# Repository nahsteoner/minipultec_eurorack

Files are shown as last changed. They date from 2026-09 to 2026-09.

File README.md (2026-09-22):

# OnerLAB BoCu

Module Eurorack **stéréo de fin de chaîne** : EQ type Pultec (sans tubes) + saturation douce à diodes + sorties jack 6,35 mm balanced.

- **Format** : 16 HP, 3U, alimentation ±12 V (header Doepfer 10 broches)
- **Entrées** : 2 × jack 3,5 mm mono (standard Eurorack), normalisées L → R
- **Sorties** : 2 × jack 6,35 mm TRS balanced (L / R)
- **PCB** : KiCad 7, netlist complète, **non routé** (placement fin + autorouter à ta main)
- **Fab** : pensé JLCPCB / LCSC, SMD 0603/0805 + SOIC-8

## Face avant

```
        OnerLAB BoCu
   [ LOW BOOST ]   [ LOW CUT ]
        [FREQ L] [FREQ R]     40 / 80 / 120 Hz
   [ MID CUT   ]   [ HIGH BOOST ]
   (LED sat L)         (LED sat R)
   IN L   IN R      OUT L   OUT R     ← jacks en bas
```

Les 4 pots sont **double piste** (L+R ensemble). Les deux rotatifs de fréquence sont **indépendants** (L et R).

## Le circuit, en une phrase

Buffer d'entrée → pad passif + mid-cut à gyrator → low-cut RC → makeup NE5532 avec **boost grave RLC (gyrator 11 H)** et **shelf aigu**, diodes Si/LED asymétriques dans la contre-réaction, puis driver balanced (hot + inverseur).

C'est un Pultec « inventé » en solide :

| Contrôle | Comportement simulé |
|---|---|
| Low boost | cloche ~+10 dB à 40 / 80 / 120 Hz, Q ≈ 1 |
| Low cut | shelf grave ~−11 dB, coin un peu au-dessus de f₀ |
| **Les deux** | le **Pultec trick** : bosse sur f₀ + creux de mud juste au-dessus |
| Mid cut | cloche ~−9 dB vers 500 Hz |
| High boost | shelf +8 à +10 dB vers 8–16 kHz |
| Diodes | propre à bas niveau (THD 0,08 % @ 0,5 V), couleur paire type lampe dès ~1,5 V |

Courbes : [`docs/curves/`](docs/curves/)

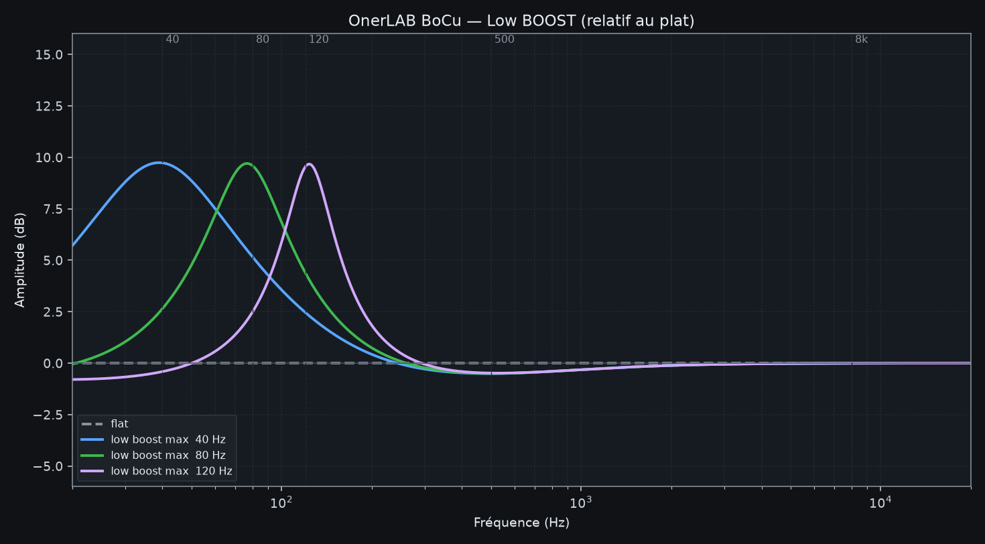
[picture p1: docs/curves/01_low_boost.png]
low boost

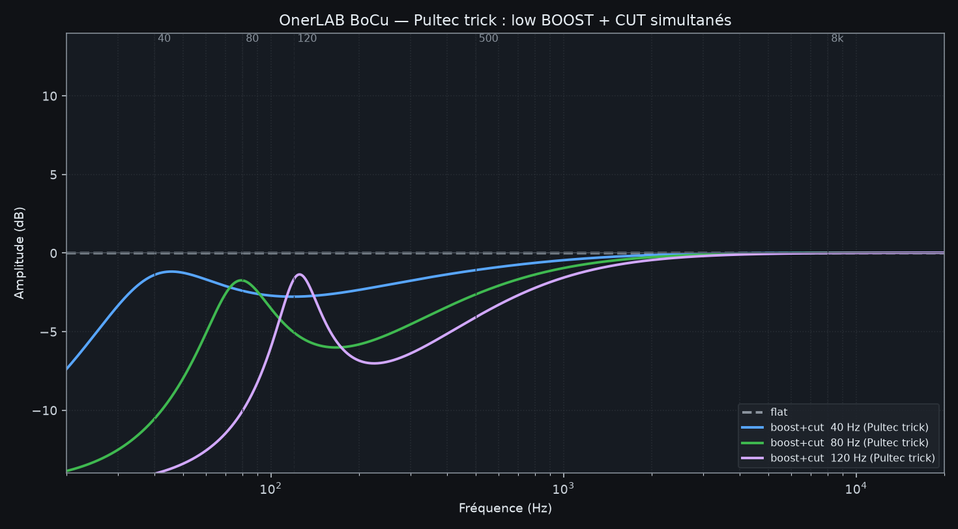
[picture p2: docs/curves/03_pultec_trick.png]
pultec trick

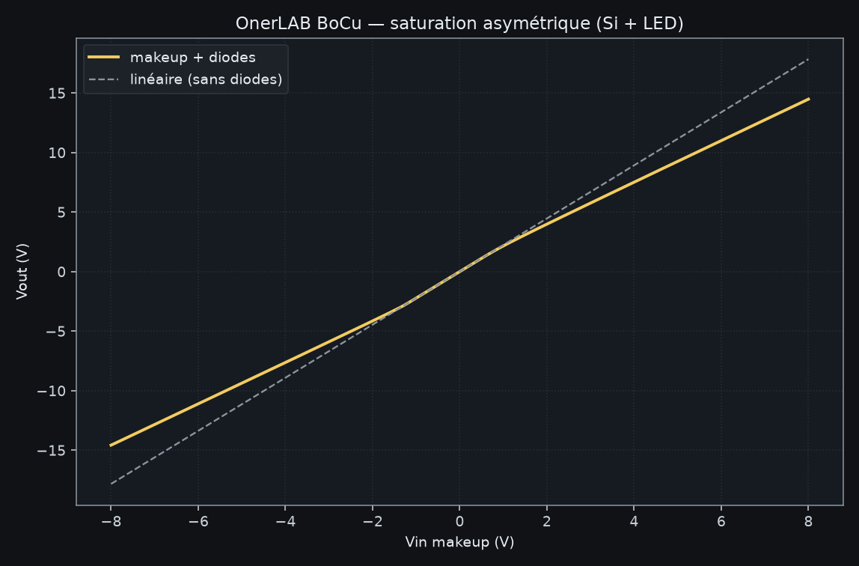
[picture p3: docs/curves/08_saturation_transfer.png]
saturation


Relancer les sims : `python3 sim/simulate_bocu.py`

## Fichiers KiCad

| Fichier | Rôle |
|---|---|
| `hardware/OnerLAB_BoCu.kicad_pcb` | PCB 78 × 118 mm, 120 footprints, **94 nets**, ratsnest prêt |
| `hardware/OnerLAB_BoCu.net` | Netlist KiCad (source de vérité électrique) |
| `hardware/OnerLAB_BoCu_panel.kicad_pcb` | Face avant 16 HP, trous uniquement |
| `hardware/BOM_LCSC.csv` | BOM + codes LCSC (SMT) |
| `hardware/libraries/` | Switch 2P3T custom |

Pas de schéma dessiné : tout part de `tools/generate_kicad.py` (SKiDL). Tu n'en as pas besoin pour router.

### Chez toi dans KiCad 7

1. Ouvre `hardware/OnerLAB_BoCu.kicad_pcb`.
2. **Place** les SMD (ils sont en grille volontairement, les jacks/pots/switchs sont déjà en zone façade).
3. Ajoute un plan de masse GND (F.Cu et/ou B.Cu).
4. Autoroute : *Route → Automatically Route Selected* / FreeRouting, ou route à la main les alimentations d'abord.
5. DRC, puis Gerber JLCPCB (2 couches, 1,6 mm, HASL ou ENIG).

Régénérer netlist + PCB vierge :

```bash
python3 tools/generate_kicad.py
python3 tools/place_pcb.py
python3 tools/make_panel.py
```

## JLCPCB / LCSC

- **SMT assemblé** : NE5532DR (`C7426`, Basic), passifs 0603/0805, BAT54S, 1N4148W SOD-123, SS14, ferrites 0805.
- **THT à souder toi-même** (pas Basic JLCPCB) :
  - 2 × Thonkiconn **PJ398SM** (entrées 3,5)
  - 2 × **Neutrik NJ3FD-V** (sorties 6,35 TRS verticales) — un jack LCSC 6,35 vertical TRS peut remplacer, **adapte le footprint**
  - 4 × Alpha **RD902** B50K dual 9 mm
  - 2 × rotatif **SR16 2P3T 16 mm** — le footprint `OnerLAB:SW_Rotary_2P3T_SR16` est un **2×4 au pas 2,54 mm** (A1 A2 A3 A / B1 B2 B3 B). **Vérifie le pinout de TON switch** avant de router, ou déplace les pads.
  - header shrouded 2×5, stripe **rouge = pin 1 = −12 V**
  - 3 × LED 3 mm (pwr + sat L/R)

Les condensateurs qui fixent 40/80/120 Hz et le gyrator 10 nF sont en 0805. Pour un son plus « studio », tu peux remplacer les C de fréquence (1 µF+470 nF, 390 nF, 150 nF, 82/39/27 nF) par du **film THT 5 mm** — laisse des pastilles si tu veux.

Codes LCSC : **revérifie le stock / Basic vs Extended** sur [jlcpcb.com/parts](https://jlcpcb.com/parts) avant commande, les C-numbers bougent.

## Alim & niveaux

- ±12 V, ~80–100 mA / rail (5 × NE5532).
- Entrée ~10 Vpp Eurorack, Z = 100 kΩ, protection BAT54S.
- Sortie balanced un peu chaude (niveau Eurorack différentiel). Un interface ligne l'accepte en général ; sinon pad dans la DAW / l'entrée.

## Mapping pots (rheostat)

| Pot | CCW | CW |
|---|---|---|
| LOW BOOST, MID, HIGH | effet min (50 k) | max (≈ 0 Ω) |
| LOW CUT | bypass (0 Ω) | max cut (50 k) |

Pistes : 1-2-3 = canal L, 4-5-6 = canal R (Alpha RD902).

## Licence / nom

OnerLAB BoCu — projet DIY personnel. Pas un clone Pultec : topologie SSD (gyrators + diodes) calquée sur le *trick* boost+cut.

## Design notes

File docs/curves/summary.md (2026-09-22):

# OnerLAB BoCu — résultats de simulation

- Gyrator low L = 11.022 H (R=33200 Ω, C=10 nF C0G)
- Gyrator mid L = 1.000 H → ~503 Hz
- Niveau plat @1 kHz = 0.06 dB (pad passif + makeup)

| Réglage | 40 Hz | 80 Hz | 200 Hz | 500 Hz | 1 kHz | 8 kHz |
|---|---:|---:|---:|---:|---:|---:|
| plat (abs dB) | -0.1 | -0.1 | -0.0 | +0.2 | +0.1 | -0.0 |
| boost 40 max | +9.7 | +5.2 | +0.4 | -0.5 | -0.3 | -0.0 |
| cut 40 max | -11.1 | -7.6 | -2.8 | -0.6 | -0.1 | +0.0 |
| trick 40 | -1.4 | -2.4 | -2.3 | -1.1 | -0.5 | +0.0 |
| trick 80 | -10.5 | -1.7 | -5.8 | -2.6 | -1.0 | +0.0 |
| trick 120 | -14.0 | -10.0 | -6.8 | -4.1 | -1.6 | -0.0 |
| mid max | +0.2 | +0.2 | -0.4 | -8.7 | -0.9 | +0.2 |
| high max | -0.0 | -0.0 | -0.2 | -0.5 | -0.3 | +7.9 |
| magic | -6.9 | -4.7 | -2.2 | -1.3 | -0.2 | +1.8 |

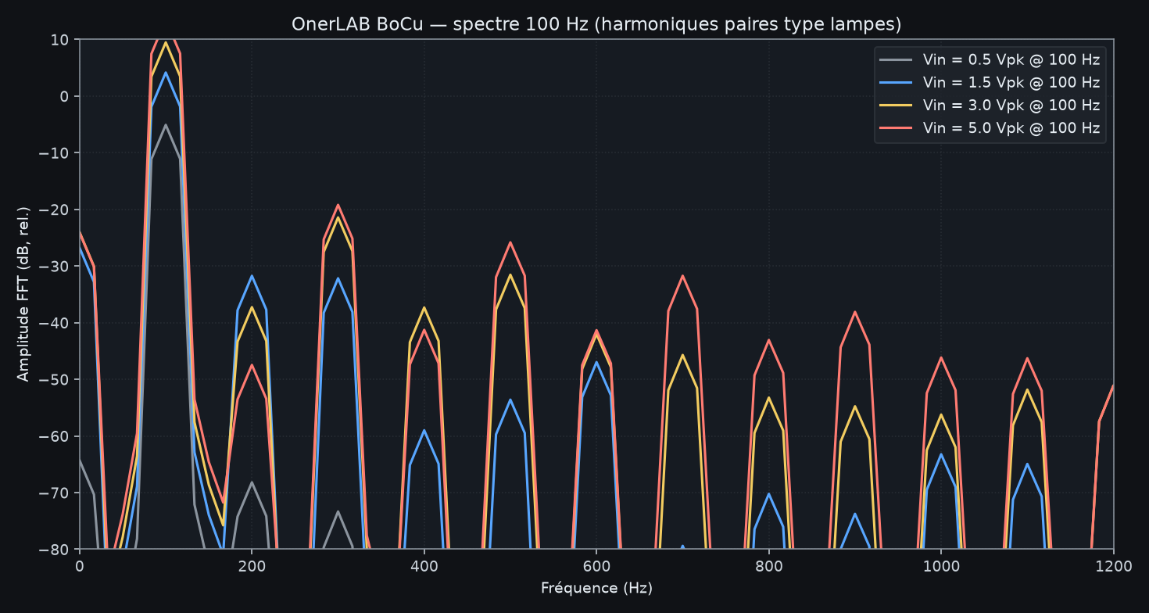
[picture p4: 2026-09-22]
docs/curves/09_saturation_spectrum.png

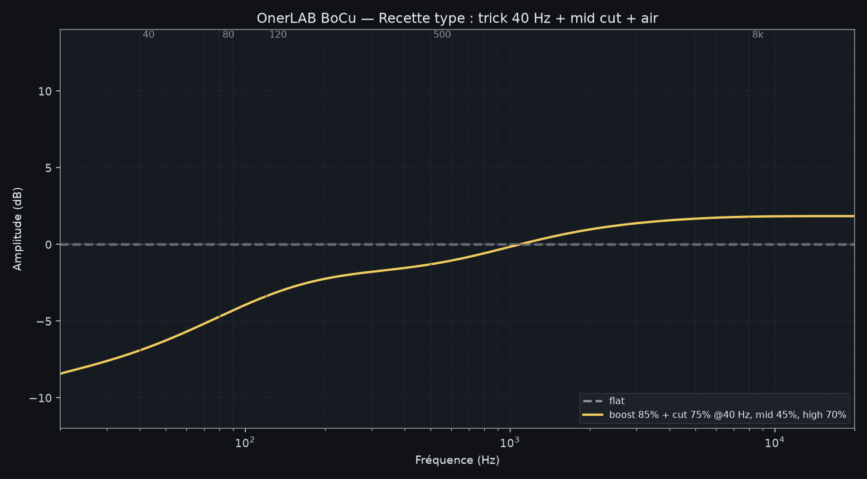
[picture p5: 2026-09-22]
docs/curves/06_magic_combo.png

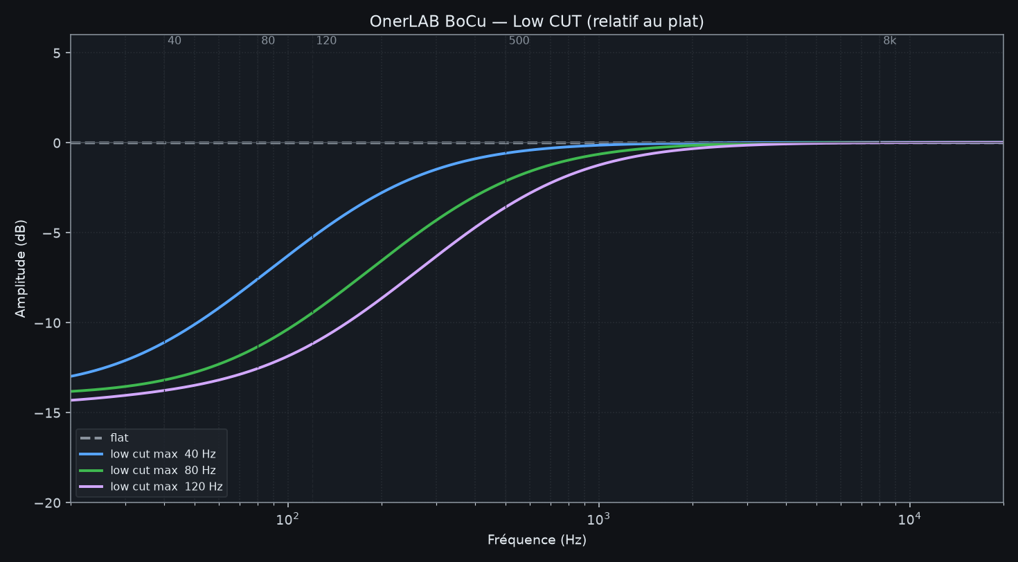
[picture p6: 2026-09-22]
docs/curves/02_low_cut.png

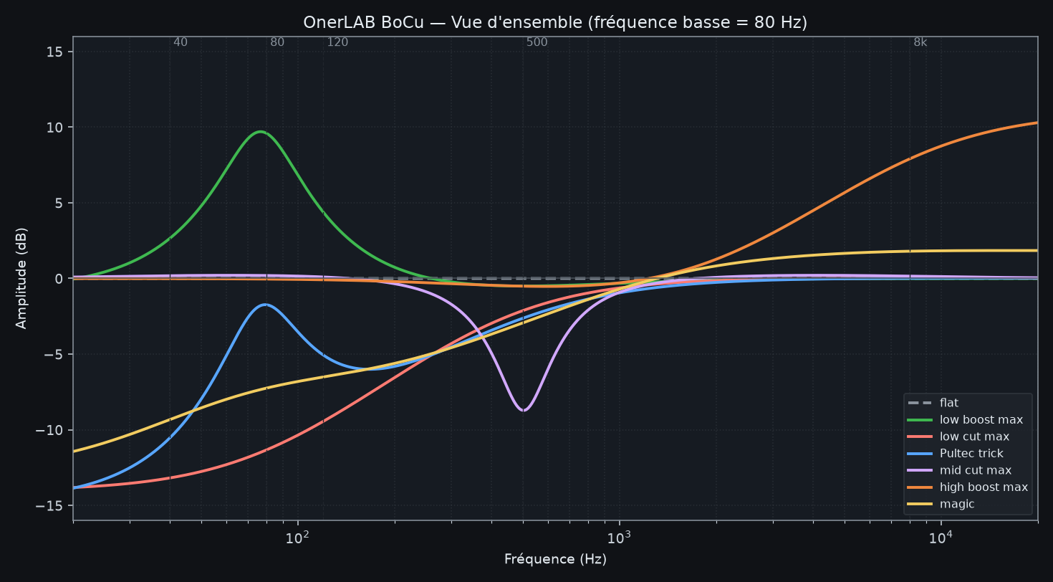
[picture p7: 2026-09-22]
docs/curves/07_all_80Hz.png

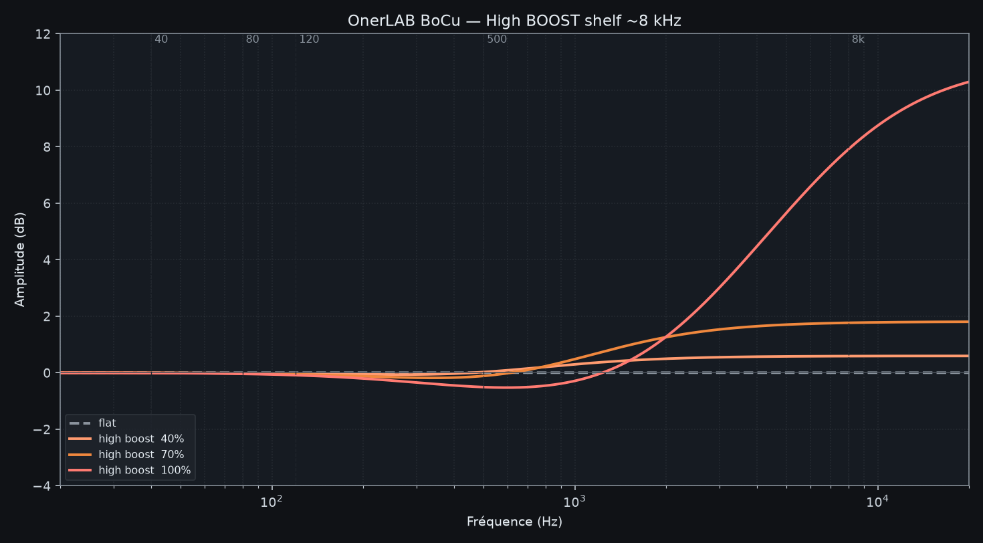
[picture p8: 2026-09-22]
docs/curves/05_high_boost.png

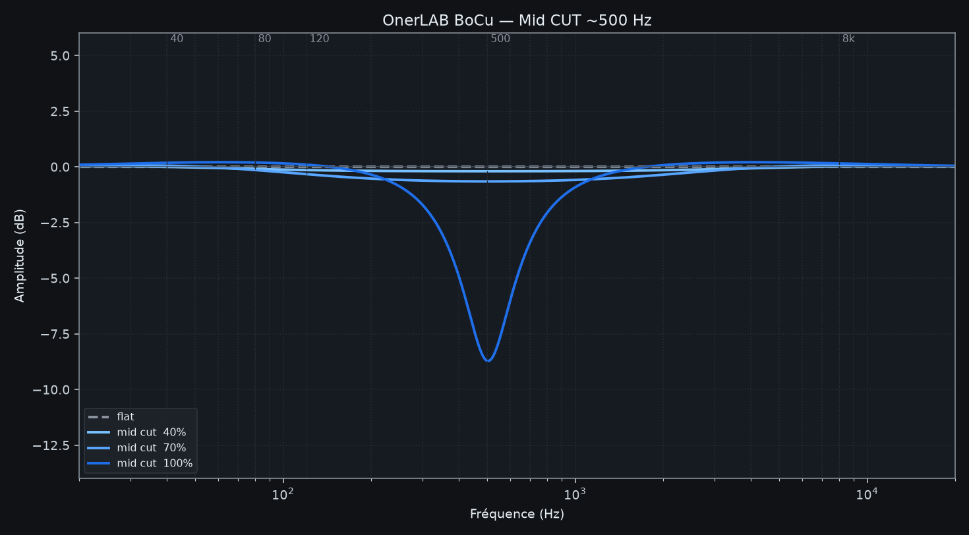
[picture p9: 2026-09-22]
docs/curves/04_mid_cut.png

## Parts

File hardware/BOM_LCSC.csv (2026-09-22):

Reference | Value | Footprint | LCSC | Mount | Notes
C10 | 100n | Capacitor_SMD:C_0603_1608Metric | C14663 | SMT
C11 | 100n | Capacitor_SMD:C_0603_1608Metric | C14663 | SMT
C12 | 100n | Capacitor_SMD:C_0603_1608Metric | C14663 | SMT
C13 | 100n | Capacitor_SMD:C_0603_1608Metric | C14663 | SMT
C14 | 100n | Capacitor_SMD:C_0603_1608Metric | C14663 | SMT
C15 | 10u | Capacitor_SMD:C_0805_2012Metric | C15850 | SMT
C16 | 100n | Capacitor_SMD:C_0805_2012Metric | C49678 | SMT
C17 | 10n | Capacitor_SMD:C_0805_2012Metric | C1710 | SMT
C18 | 82n | Capacitor_SMD:C_0805_2012Metric | C39616 | SMT
C19 | 39n | Capacitor_SMD:C_0805_2012Metric | C1653 | SMT
C2 | 100n | Capacitor_SMD:C_0603_1608Metric | C14663 | SMT
C20 | 27n | Capacitor_SMD:C_0805_2012Metric | C1548 | SMT
C21 | 8.2n | Capacitor_SMD:C_0805_2012Metric | C1804 | SMT
C22 | 1u | Capacitor_SMD:C_0805_2012Metric | C28323 | SMT
C23 | 470n | Capacitor_SMD:C_0805_2012Metric | C1713 | SMT
C24 | 390n | Capacitor_SMD:C_0805_2012Metric | C1328 | SMT
C25 | 150n | Capacitor_SMD:C_0805_2012Metric | C66719 | SMT
C26 | 10n | Capacitor_SMD:C_0805_2012Metric | C1710 | SMT
C27 | 10u | Capacitor_SMD:C_0805_2012Metric | C15850 | SMT
C28 | 10u | Capacitor_SMD:C_0805_2012Metric | C15850 | SMT
C29 | 10u | Capacitor_SMD:C_0805_2012Metric | C15850 | SMT
C30 | 100n | Capacitor_SMD:C_0805_2012Metric | C49678 | SMT
C31 | 10n | Capacitor_SMD:C_0805_2012Metric | C1710 | SMT
C32 | 82n | Capacitor_SMD:C_0805_2012Metric | C39616 | SMT
C33 | 39n | Capacitor_SMD:C_0805_2012Metric | C1653 | SMT
C34 | 27n | Capacitor_SMD:C_0805_2012Metric | C1548 | SMT
C35 | 8.2n | Capacitor_SMD:C_0805_2012Metric | C1804 | SMT
C36 | 1u | Capacitor_SMD:C_0805_2012Metric | C28323 | SMT
C37 | 470n | Capacitor_SMD:C_0805_2012Metric | C1713 | SMT
C38 | 390n | Capacitor_SMD:C_0805_2012Metric | C1328 | SMT
C39 | 150n | Capacitor_SMD:C_0805_2012Metric | C66719 | SMT
C4 | 100n | Capacitor_SMD:C_0603_1608Metric | C14663 | SMT
C40 | 10n | Capacitor_SMD:C_0805_2012Metric | C1710 | SMT
C41 | 10u | Capacitor_SMD:C_0805_2012Metric | C15850 | SMT
C42 | 10u | Capacitor_SMD:C_0805_2012Metric | C15850 | SMT
C5 | 100n | Capacitor_SMD:C_0603_1608Metric | C14663 | SMT
C6 | 100n | Capacitor_SMD:C_0603_1608Metric | C14663 | SMT
C7 | 100n | Capacitor_SMD:C_0603_1608Metric | C14663 | SMT
C8 | 100n | Capacitor_SMD:C_0603_1608Metric | C14663 | SMT
C80 | 10u | Capacitor_SMD:C_0805_2012Metric | C15850 | SMT
C81 | 10u | Capacitor_SMD:C_0805_2012Metric | C15850 | SMT
C9 | 100n | Capacitor_SMD:C_0603_1608Metric | C14663 | SMT
D10 | SS14 | Diode_SMD:D_SMA | C8678 | SMT
D11 | SS14 | Diode_SMD:D_SMA | C8678 | SMT
D12 | LED_PWR | LED_THT:LED_D3.0mm | C72038 | THT
D13 | 1N4148W | Diode_SMD:D_SOD-123 | C2128 | SMT
D14 | 1N4148W | Diode_SMD:D_SOD-123 | C2128 | SMT
D15 | 1N4148W | Diode_SMD:D_SOD-123 | C2128 | SMT
D16 | LED_SAT | LED_THT:LED_D3.0mm | C72038 | THT
D4 | BAT54S | Package_TO_SOT_SMD:SOT-23 | C8547 | SMT
D5 | 1N4148W | Diode_SMD:D_SOD-123 | C2128 | SMT
D6 | 1N4148W | Diode_SMD:D_SOD-123 | C2128 | SMT
D7 | 1N4148W | Diode_SMD:D_SOD-123 | C2128 | SMT
D8 | LED_SAT | LED_THT:LED_D3.0mm | C72038 | THT
D9 | BAT54S | Package_TO_SOT_SMD:SOT-23 | C8547 | SMT
FB1 | 600R@100MHz | Inductor_SMD:L_0805_2012Metric | C16762 | SMT
FB2 | 600R@100MHz | Inductor_SMD:L_0805_2012Metric | C16762 | SMT
J1 | IN_L_3.5 | Connector_Audio:Jack_3.5mm_QingPu_WQP-PJ398SM_Vertical_CircularHoles |  | THTThonk PJ398SM / WQP-PJ398SM (pas JLCPCB)
J2 | IN_R_3.5 | Connector_Audio:Jack_3.5mm_QingPu_WQP-PJ398SM_Vertical_CircularHoles |  | THTThonk PJ398SM / WQP-PJ398SM (pas JLCPCB)
J3 | OUT_L_6.35 | Connector_Audio:Jack_6.35mm_Neutrik_NJ3FD-V_Vertical |  | THTNeutrik NJ3FD-V — alt. LCSC jack 6.35 TRS vertical
J4 | OUT_R_6.35 | Connector_Audio:Jack_6.35mm_Neutrik_NJ3FD-V_Vertical |  | THTNeutrik NJ3FD-V — alt. LCSC jack 6.35 TRS vertical
J5 | EURORACK_10P | Connector_IDC:IDC-Header_2x05_P2.54mm_Vertical |  | THTHeader shrouded 2x5 2.54mm | stripe rouge = pin1 = -12V
R1 | 10k | Resistor_SMD:R_0603_1608Metric | C25803 | SMT
R10 | 15k | Resistor_SMD:R_0603_1608Metric | C22847 | SMT
R11 | 2.2k | Resistor_SMD:R_0603_1608Metric | C17630 | SMT
R12 | 10k | Resistor_SMD:R_0603_1608Metric | C25803 | SMT
R13 | 22k | Resistor_SMD:R_0603_1608Metric | C14611 | SMT
R14 | 22k | Resistor_SMD:R_0603_1608Metric | C14611 | SMT
R15 | 2.2k | Resistor_SMD:R_0603_1608Metric | C17630 | SMT
R16 | 2.7k | Resistor_SMD:R_0603_1608Metric | C22933 | SMT
R17 | 33k | Resistor_SMD:R_0603_1608Metric | C23214 | SMT
R18 | 33k | Resistor_SMD:R_0603_1608Metric | C23214 | SMT
R19 | 10k | Resistor_SMD:R_0603_1608Metric | C25803 | SMT
R2 | 100k | Resistor_SMD:R_0603_1608Metric | C1790 | SMT
R20 | 10k | Resistor_SMD:R_0603_1608Metric | C25803 | SMT
R21 | 220R | Resistor_SMD:R_0603_1608Metric | C14754 | SMT
R22 | 100k | Resistor_SMD:R_0603_1608Metric | C1790 | SMT
R23 | 220R | Resistor_SMD:R_0603_1608Metric | C14754 | SMT
R24 | 100k | Resistor_SMD:R_0603_1608Metric | C1790 | SMT
R25 | 100k | Resistor_SMD:R_0603_1608Metric | C1790 | SMT
R26 | 1k | Resistor_SMD:R_0603_1608Metric | C11702 | SMT
R27 | 4.7k | Resistor_SMD:R_0603_1608Metric | C13305 | SMT
R28 | 4.7k | Resistor_SMD:R_0603_1608Metric | C13305 | SMT
R29 | 1k | Resistor_SMD:R_0603_1608Metric | C11702 | SMT
R3 | 1k | Resistor_SMD:R_0603_1608Metric | C11702 | SMT
R30 | 10k | Resistor_SMD:R_0603_1608Metric | C25803 | SMT
R31 | 10k | Resistor_SMD:R_0603_1608Metric | C25803 | SMT
R32 | 10k | Resistor_SMD:R_0603_1608Metric | C25803 | SMT
R33 | 15k | Resistor_SMD:R_0603_1608Metric | C22847 | SMT
R34 | 2.2k | Resistor_SMD:R_0603_1608Metric | C17630 | SMT
R35 | 10k | Resistor_SMD:R_0603_1608Metric | C25803 | SMT
R36 | 22k | Resistor_SMD:R_0603_1608Metric | C14611 | SMT
R37 | 22k | Resistor_SMD:R_0603_1608Metric | C14611 | SMT
R38 | 2.2k | Resistor_SMD:R_0603_1608Metric | C17630 | SMT
R39 | 2.7k | Resistor_SMD:R_0603_1608Metric | C22933 | SMT
R4 | 4.7k | Resistor_SMD:R_0603_1608Metric | C13305 | SMT
R40 | 33k | Resistor_SMD:R_0603_1608Metric | C23214 | SMT
R41 | 33k | Resistor_SMD:R_0603_1608Metric | C23214 | SMT
R42 | 10k | Resistor_SMD:R_0603_1608Metric | C25803 | SMT
R43 | 10k | Resistor_SMD:R_0603_1608Metric | C25803 | SMT
R44 | 220R | Resistor_SMD:R_0603_1608Metric | C14754 | SMT
R45 | 100k | Resistor_SMD:R_0603_1608Metric | C1790 | SMT
R46 | 220R | Resistor_SMD:R_0603_1608Metric | C14754 | SMT
R47 | 100k | Resistor_SMD:R_0603_1608Metric | C1790 | SMT
R5 | 4.7k | Resistor_SMD:R_0603_1608Metric | C13305 | SMT
R6 | 1k | Resistor_SMD:R_0603_1608Metric | C11702 | SMT
R7 | 10k | Resistor_SMD:R_0603_1608Metric | C25803 | SMT
R8 | 10k | Resistor_SMD:R_0603_1608Metric | C25803 | SMT
R9 | 10k | Resistor_SMD:R_0603_1608Metric | C25803 | SMT
RV1 | B50K_BOOST | Potentiometer_THT:Potentiometer_Alpha_RD902F-40-00D_Dual_Vertical |  | THTAlpha RD902F B50K dual 9mm (Thonk / modular)
RV2 | B50K_CUT | Potentiometer_THT:Potentiometer_Alpha_RD902F-40-00D_Dual_Vertical |  | THTAlpha RD902F B50K dual 9mm
RV3 | B50K_MID | Potentiometer_THT:Potentiometer_Alpha_RD902F-40-00D_Dual_Vertical |  | THTAlpha RD902F B50K dual 9mm
RV4 | B50K_HIGH | Potentiometer_THT:Potentiometer_Alpha_RD902F-40-00D_Dual_Vertical |  | THTAlpha RD902F B50K dual 9mm
SW1 | FREQ_L | OnerLAB:SW_Rotary_2P3T_SR16 |  | THTSR16 2P3T 16mm — VERIFIER le pinout vs footprint OnerLAB
SW2 | FREQ_R | OnerLAB:SW_Rotary_2P3T_SR16 |  | THTSR16 2P3T 16mm — VERIFIER le pinout vs footprint OnerLAB
U1 | NE5532DR | Package_SO:SOIC-8_3.9x4.9mm_P1.27mm | C7426 | SMT
U2 | NE5532DR | Package_SO:SOIC-8_3.9x4.9mm_P1.27mm | C7426 | SMT
U3 | NE5532DR | Package_SO:SOIC-8_3.9x4.9mm_P1.27mm | C7426 | SMT
U4 | NE5532DR | Package_SO:SOIC-8_3.9x4.9mm_P1.27mm | C7426 | SMT
U5 | NE5532DR | Package_SO:SOIC-8_3.9x4.9mm_P1.27mm | C7426 | SMT

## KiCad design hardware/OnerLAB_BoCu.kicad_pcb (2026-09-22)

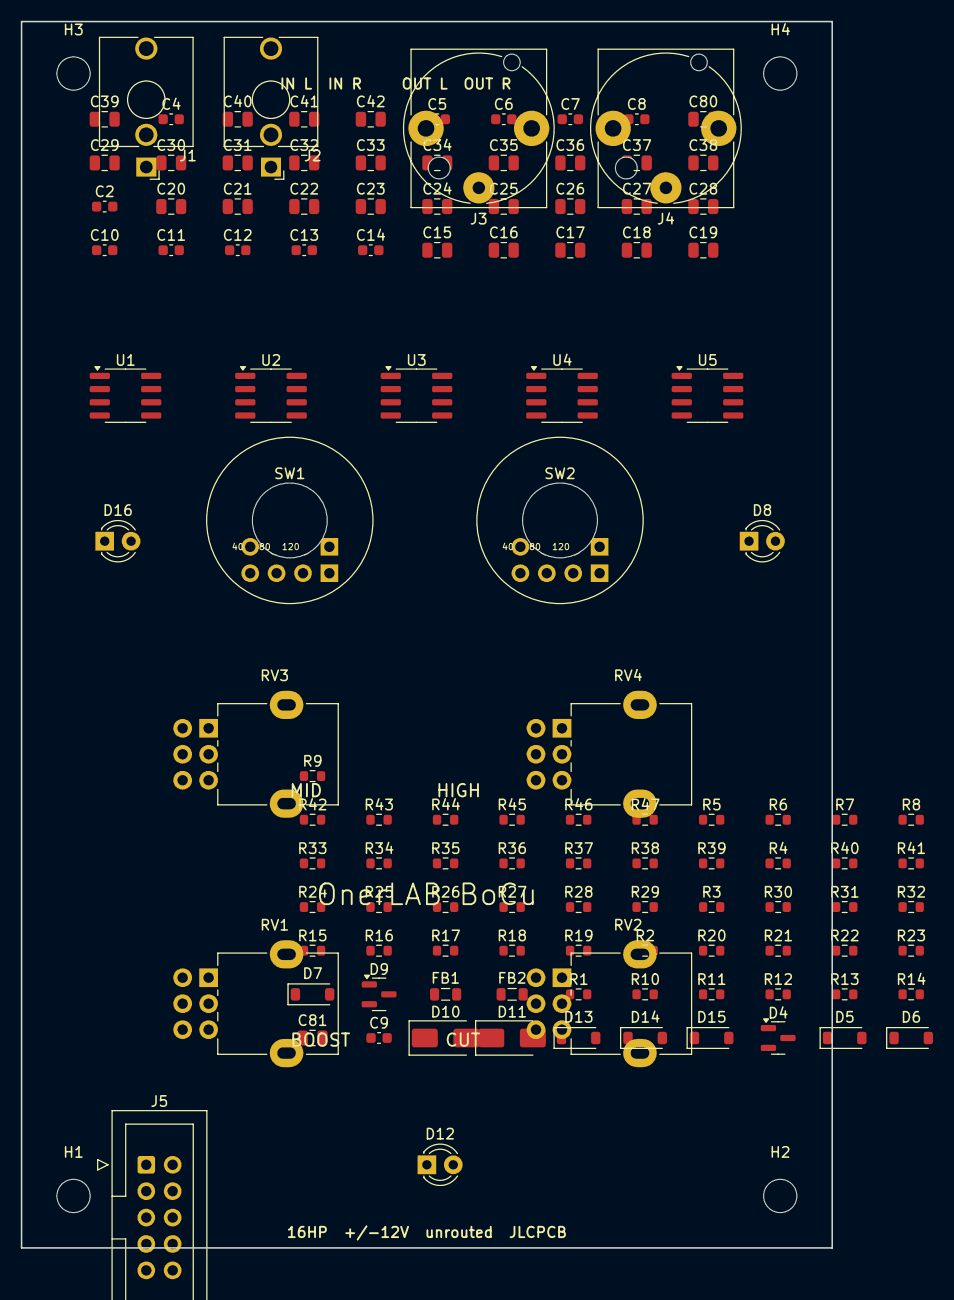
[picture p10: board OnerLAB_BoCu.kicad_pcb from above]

Board: 2 copper layers, 78.0 x 118.0 mm, 124 parts (0 on the bottom side), 82 nets, no tracks yet.

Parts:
C2, C4, C5, C6, C7, C8, C9, C10, C11, C12, C13, C14: 100n; C_0603_1608Metric
C15, C27, C28, C29, C41, C42, C80, C81: 10u; C_0805_2012Metric
C16, C30: 100n; C_0805_2012Metric
C17, C26, C31, C40: 10n; C_0805_2012Metric
C18, C32: 82n; C_0805_2012Metric
C19, C33: 39n; C_0805_2012Metric
C20, C34: 27n; C_0805_2012Metric
C21, C35: 8.2n; C_0805_2012Metric
C22, C36: 1u; C_0805_2012Metric
C23, C37: 470n; C_0805_2012Metric
C24, C38: 390n; C_0805_2012Metric
C25, C39: 150n; C_0805_2012Metric
D4, D9: BAT54S; SOT-23
D5, D6, D7, D13, D14, D15: 1N4148W; D_SOD-123
D8, D16: LED_SAT; LED_D3.0mm
D10, D11: SS14; D_SMA
D12: LED_PWR; LED_D3.0mm
FB1, FB2: 600R@100MHz; L_0805_2012Metric
H1, H2, H3, H4: M3; MountingHole_3.2mm_M3
J1: IN_L_3.5; Jack_3.5mm_QingPu_WQP-PJ398SM_Vertical_CircularHoles
J2: IN_R_3.5; Jack_3.5mm_QingPu_WQP-PJ398SM_Vertical_CircularHoles
J3: OUT_L_6.35; Jack_6.35mm_Neutrik_NJ3FD-V_Vertical
J4: OUT_R_6.35; Jack_6.35mm_Neutrik_NJ3FD-V_Vertical
J5: EURORACK_10P; IDC-Header_2x05_P2.54mm_Vertical
R1, R7, R8, R9, R12, R19, R20, R30, R31, R32, R35, R42, R43: 10k; R_0603_1608Metric
R2, R22, R24, R25, R45, R47: 100k; R_0603_1608Metric
R3, R6, R26, R29: 1k; R_0603_1608Metric
R4, R5, R27, R28: 4.7k; R_0603_1608Metric
R10, R33: 15k; R_0603_1608Metric
R11, R15, R34, R38: 2.2k; R_0603_1608Metric
R13, R14, R36, R37: 22k; R_0603_1608Metric
R16, R39: 2.7k; R_0603_1608Metric
R17, R18, R40, R41: 33k; R_0603_1608Metric
R21, R23, R44, R46: 220R; R_0603_1608Metric
RV1: B50K_BOOST; Potentiometer_Alpha_RD902F-40-00D_Dual_Vertical
RV2: B50K_CUT; Potentiometer_Alpha_RD902F-40-00D_Dual_Vertical
RV3: B50K_MID; Potentiometer_Alpha_RD902F-40-00D_Dual_Vertical
RV4: B50K_HIGH; Potentiometer_Alpha_RD902F-40-00D_Dual_Vertical
SW1: FREQ_L; SW_Rotary_2P3T_SR16
SW2: FREQ_R; SW_Rotary_2P3T_SR16
U1, U2, U3, U4, U5: NE5532DR; SOIC-8_3.9x4.9mm_P1.27mm

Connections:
+12V: C2.1, C5.1, C7.1, C9.1, C11.1, C13.1, C80.1, D4.2, D9.2, FB1.2, R1.1, U1.8, U2.8, U3.8, U4.8, U5.8
-12V: C4.1, C6.1, C8.1, C10.1, C12.1, C14.1, C81.1, D4.1, D9.1, FB2.2, U1.4, U2.4, U3.4, U4.4, U5.4
GND: C2.2, C4.2, C5.2, C6.2, C7.2, C8.2, C9.2, C10.2, C11.2, C12.2, C13.2, C14.2, C17.2, C21.2, C26.2, C31.2, C35.2, C40.2, C80.2, C81.2, D12.1, J1.S, J2.S, J3.S, J4.S, J5.2, J5.3, J5.4, J5.5, J5.6, R2.2, R5.2, R9.2, R12.2, R22.2, R24.2, R25.2, R28.2, R32.2, R35.2, R45.2, R47.2, U2.5, U4.5
IN_L: C15.1, J1.T, J2.TN, R2.1
IN_R: C29.1, J2.T, R25.1
L_BLK: D4.3, R3.2, U1.3
L_BUF: R4.1, U1.1, U1.2
L_COLD: R20.2, R23.1, U2.7
L_D3: D7.1, R13.1
L_EQ: R4.2, R5.1, R6.1, RV2.1, SW1.B
L_HI: R15.2, RV4.2
L_INVN: R19.2, R20.1, U2.6
L_LB: R16.2, RV1.2
L_LC: RV1.3, SW1.A
L_LG+: C26.1, R17.2, U1.5
L_LL: C22.2, C23.2, C24.2, C25.2, R17.1, R18.2
L_MIDC: C16.1, RV3.3
L_MIDG+: C17.1, R7.2, U5.3
L_MIDL: C16.2, R7.1, R8.2
L_MIDW: R6.2, RV3.2
L_MK: D5.2, R10.1, R14.2, R19.1, R21.1, U2.1
L_NINV: D8.2, R10.2, R11.1, R13.2, R15.1, R16.1, U2.2
L_POST: C18.2, C19.2, C20.2, R9.1, RV2.2, U2.3
L_TAP: R11.2, R12.1
unnamed: D10.1, FB1.1
unnamed: D11.2, FB2.1
unnamed: D12.2, R1.2
unnamed: C15.2, R3.1
unnamed: R8.1, U5.1, U5.2
unnamed: C18.1, SW1.B1
unnamed: C19.1, SW1.B2
unnamed: C20.1, SW1.B3
unnamed: D5.1, D6.2
unnamed: D6.1, D7.2
unnamed: D8.1, R14.1
unnamed: C21.1, RV4.3
unnamed: C22.1, C23.1, SW1.A1
unnamed: C24.1, SW1.A2
unnamed: C25.1, SW1.A3
unnamed: R18.1, U1.6, U1.7
unnamed: C27.2, J3.T, R22.1
unnamed: C27.1, R21.2
unnamed: C28.2, J3.R, R24.1
unnamed: C28.1, R23.2
unnamed: C29.2, R26.1
unnamed: R31.1, U5.6, U5.7
unnamed: C32.1, SW2.B1
unnamed: C33.1, SW2.B2
unnamed: C34.1, SW2.B3
unnamed: D13.1, D14.2
unnamed: D14.1, D15.2
unnamed: D16.1, R37.1
unnamed: C35.1, RV4.6
unnamed: C36.1, C37.1, SW2.A1
unnamed: C38.1, SW2.A2
unnamed: C39.1, SW2.A3
unnamed: R41.1, U3.6, U3.7
unnamed: C41.2, J4.T, R45.1
unnamed: C41.1, R44.2
unnamed: C42.2, J4.R, R47.1
unnamed: C42.1, R46.2
RAW+12: D10.2, J5.7, J5.8
RAW-12: D11.1, J5.1
R_BLK: D9.3, R26.2, U3.3
R_BUF: R27.1, U3.1, U3.2
R_COLD: R43.2, R46.1, U4.7
R_D3: D15.1, R36.1
R_EQ: R27.2, R28.1, R29.1, RV2.4, SW2.B
R_HI: R38.2, RV4.5
R_INVN: R42.2, R43.1, U4.6
R_LB: R39.2, RV1.5
R_LC: RV1.6, SW2.A
R_LG+: C40.1, R40.2, U3.5
R_LL: C36.2, C37.2, C38.2, C39.2, R40.1, R41.2
R_MIDC: C30.1, RV3.6
R_MIDG+: C31.1, R30.2, U5.5
R_MIDL: C30.2, R30.1, R31.2
R_MIDW: R29.2, RV3.5
R_MK: D13.2, R33.1, R37.2, R42.1, R44.1, U4.1
R_NINV: D16.2, R33.2, R34.1, R36.2, R38.1, R39.1, U4.2
R_POST: C32.2, C33.2, C34.2, R32.1, RV2.5, U4.3
R_TAP: R34.2, R35.1

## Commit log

2026-09-22 Add OnerLAB BoCu 16HP stereo Pultec-style output module
    Solid-state EQ (gyrator low boost, RC low cut, 500 Hz mid cut, high shelf)
    with asymmetric diode saturation and balanced 6.35 mm outs. KiCad 7 PCB
    ships with a complete netlist and LCSC-oriented SMD BOM; placement of SMT
    is left for the user plus autorouter. Includes simulated frequency and
    saturation curves.
    [BOM_LCSC.csv, OnerLAB_BoCu.kicad_pcb, OnerLAB_BoCu_panel.kicad_pcb]
2026-09-22 Ignore KiCad local files and SKiDL ERC logs
